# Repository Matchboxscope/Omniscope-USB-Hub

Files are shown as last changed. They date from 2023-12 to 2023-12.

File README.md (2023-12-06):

# SL2.1A Type-C Hub

Based on: https://github.com/Hugoyhu/SL2.1A-Type-C-Hub

A simple 4-port USB2 hub based on the SL2.1A design.
This board is designed in KiCAD v7! It is based off an earlier [2021 design](https://github.com/Hugoyhu/Hack-Club-Zephyr-USB-Hub) with USB-A outputs.

This revises the board to provide USB2 Type-C outputs. By default, the schematic provides circuitry for default USB power (500mA) but resistor values can be changed to provide higher output current if available through external power.

Schematic Capture
PCB Render
Assembled OSHPark After Dark

These boards have been tested and built with OSHPark After Dark service.

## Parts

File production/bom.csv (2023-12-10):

Designator | Footprint | Quantity | Value | LCSC Part #
C1, C11, C5, C7, C9 | 0805 | 5 | 100nF
C10, C4, C6, C8 | 0805 | 4 | 1uF
C2, C3 | 0805 | 2 | 10uF
D1 | 1206 | 1 | SD1206T020S1R0
D2 | 1206 | 1 | LED_Small
H1, H2 | MountingHole_3.2mm_M3_ISO14580 | 2 | MountingHole
J1 | USB_C_Receptacle_HRO_TYPE-C-31-M-12 | 1 | USB_C_Receptacle_USB2.0
J2, J3, J4, J5 | USB_C_Plug_UTC009-C12 | 4 | USB_C_Receptacle_USB2.0
R1, R2 | 0805 | 2 | 5.1K
R10, R3, R4, R5, R6, R7, R8, R9 | 0805 | 8 | 56K
R11 | 0805 | 1 | 100
U1 | SOIC-16_4.55x10.3mm_P1.27mm | 1 | SL2.1A

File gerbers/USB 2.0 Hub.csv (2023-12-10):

Id | Designator | Footprint | Quantity | Designation | Supplier and ref
1 | C4,C6,C10,C8 | C_0805_2012Metric_Pad1.18x1.45mm_HandSolder | 4 | 1uF
2 | H2,H1 | MountingHole_3.2mm_M3_ISO14580 | 2 | MountingHole
3 | R11 | R_0805_2012Metric_Pad1.20x1.40mm_HandSolder | 1 | 100
4 | C1,C9,C11,C5,C7 | C_0805_2012Metric_Pad1.18x1.45mm_HandSolder | 5 | 100nF
5 | R1,R2 | R_0805_2012Metric_Pad1.20x1.40mm_HandSolder | 2 | 5.1K
6 | D2 | LED_1206_3216Metric_Pad1.42x1.75mm_HandSolder | 1 | LED_Small
7 | R6,R4,R10,R3,R5,R8,R9,R7 | R_0805_2012Metric_Pad1.20x1.40mm_HandSolder | 8 | 56K
8 | J2,J3,J5,J4 | USB_C_Plug_UTC009-C12 | 4 | USB_C_Receptacle_USB2.0
9 | C2,C3 | C_0805_2012Metric_Pad1.18x1.45mm_HandSolder | 2 | 10uF
10 | U1 | SOIC-16_4.55x10.3mm_P1.27mm | 1 | SL2.1A
11 | D1 | D_1206_3216Metric_Pad1.42x1.75mm_HandSolder | 1 | SD1206T020S1R0
12 | J1 | USB_C_Receptacle_HRO_TYPE-C-31-M-12 | 1 | USB_C_Receptacle_USB2.0

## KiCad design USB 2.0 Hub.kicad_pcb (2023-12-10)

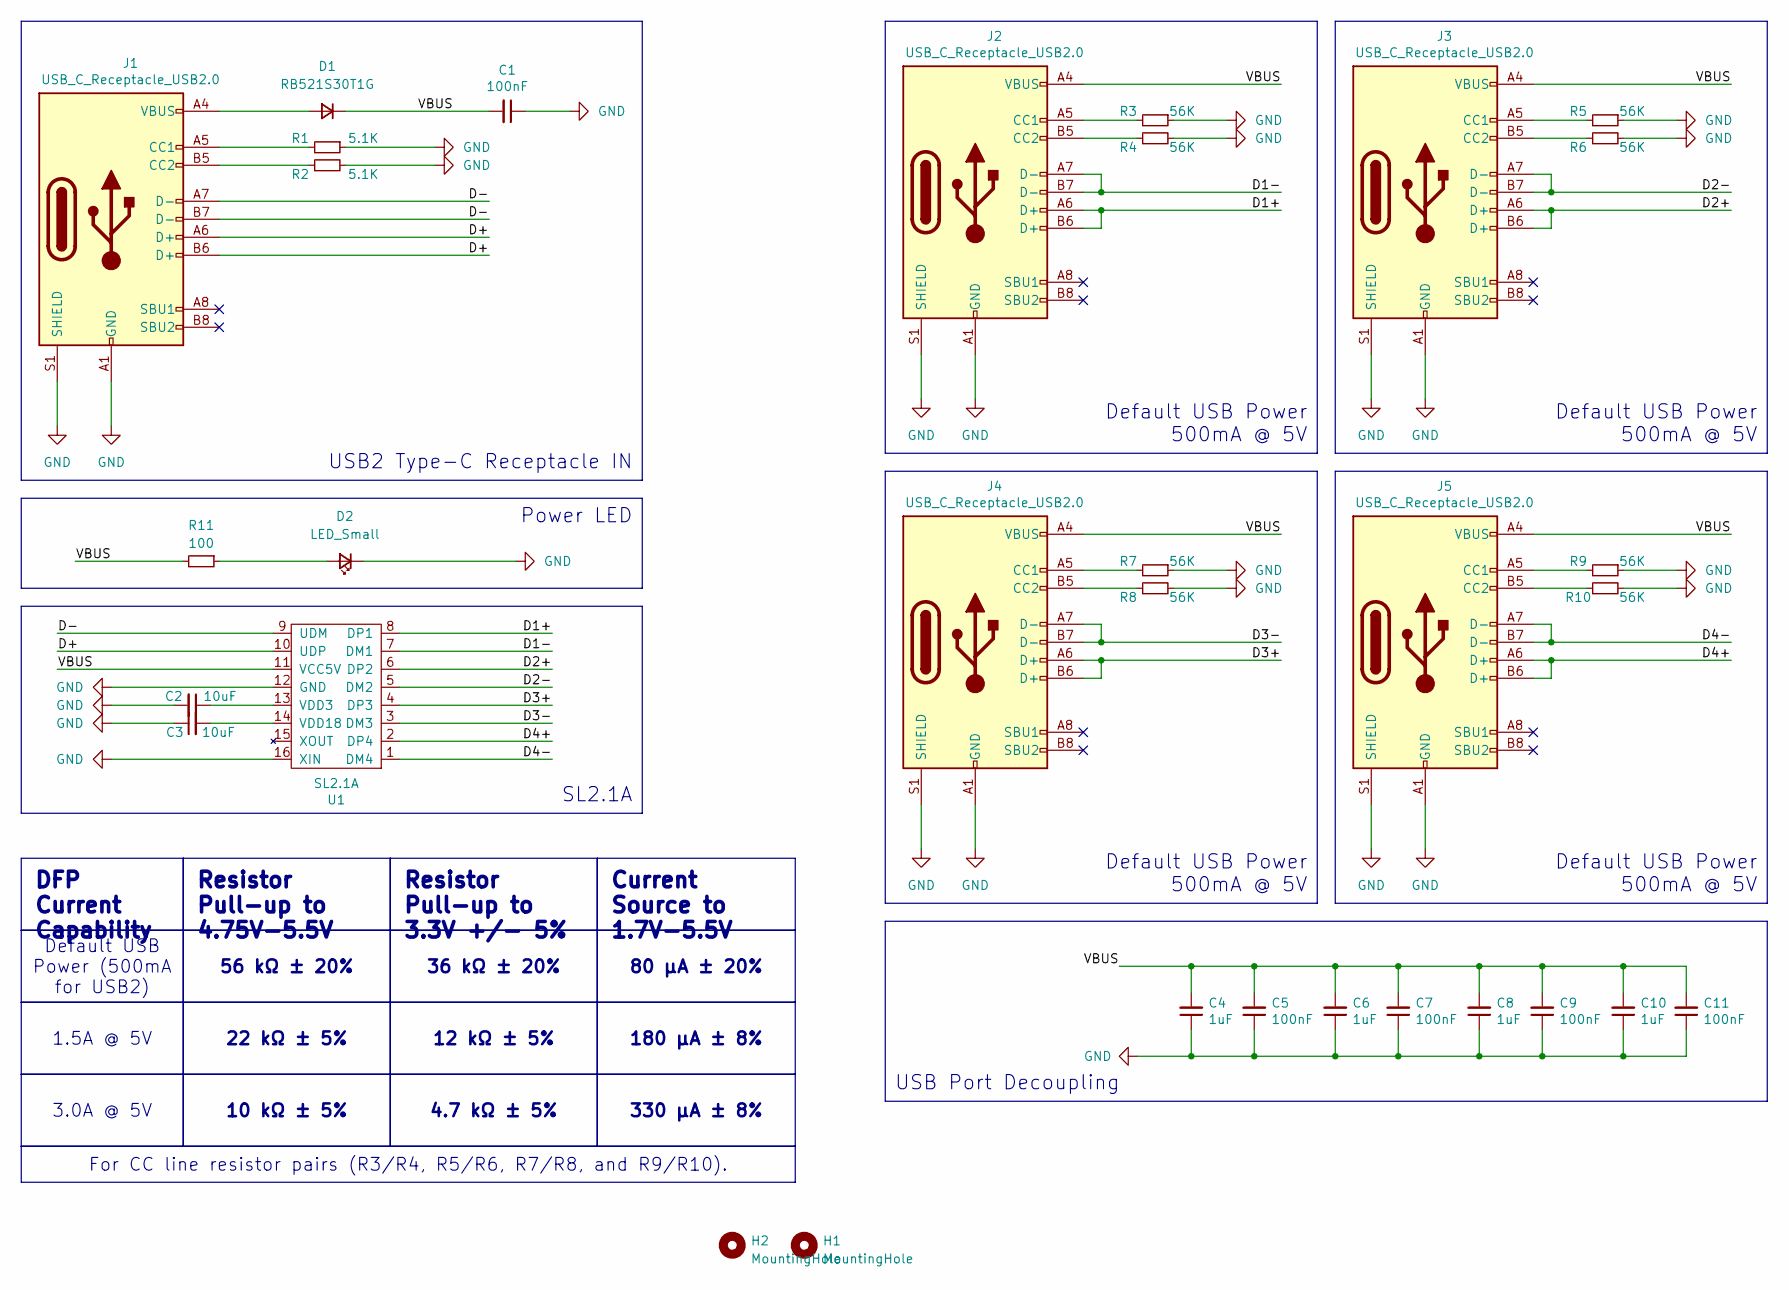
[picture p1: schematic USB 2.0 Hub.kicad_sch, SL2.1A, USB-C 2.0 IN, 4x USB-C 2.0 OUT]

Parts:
C1, C5, C7, C9, C11: 100nF; C_0805_2012Metric_Pad1.18x1.45mm_HandSolder
C2, C3: 10uF; C_0805_2012Metric_Pad1.18x1.45mm_HandSolder
C4, C6, C8, C10: 1uF; C_0805_2012Metric_Pad1.18x1.45mm_HandSolder
D1: RB521S30T1G; D_SOD-523
D2: LED_Small; LED_1206_3216Metric_Pad1.42x1.75mm_HandSolder
H1, H2: MountingHole; MountingHole_3.2mm_M3_ISO14580
J1: USB_C_Receptacle_USB2.0; USB_C_Receptacle_HRO_TYPE-C-31-M-12
J2, J3, J4, J5: USB_C_Receptacle_USB2.0; USB_C_Receptacle_U261-241N-4BS2SS
R1, R2: 5.1K; R_0805_2012Metric_Pad1.20x1.40mm_HandSolder
R3, R4, R5, R6, R7, R8, R9, R10: 56K; R_0805_2012Metric_Pad1.20x1.40mm_HandSolder
R11: 100; R_0805_2012Metric_Pad1.20x1.40mm_HandSolder
U1: SL2.1A; SOIC-16_4.55x10.3mm_P1.27mm

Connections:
/D1+: J2.A6 (D+), J2.B6 (D+), U1.8 (DP1)
/D1-: J2.A7 (D-), J2.B7 (D-), U1.7 (DM1)
/D2+: J3.A6 (D+), J3.B6 (D+), U1.6 (DP2)
/D2-: J3.A7 (D-), J3.B7 (D-), U1.5 (DM2)
/D3+: J4.A6 (D+), J4.B6 (D+), U1.4 (DP3)
/D3-: J4.A7 (D-), J4.B7 (D-), U1.3 (DM3)
/D4+: J5.A6 (D+), J5.B6 (D+), U1.2 (DP4)
/D4-: J5.A7 (D-), J5.B7 (D-), U1.1 (DM4)
/D+: J1.A6 (D+), J1.B6 (D+), U1.10 (UDP)
/D-: J1.A7 (D-), J1.B7 (D-), U1.9 (UDM)
/VBUS: C1.2, C4.2, C5.2, C6.2, C7.2, C8.2, C9.2, C10.2, C11.2, D1.1 (K), J2.A4 (VBUS), J2.A9 (VBUS), J2.B4 (VBUS), J2.B9 (VBUS), J3.A4 (VBUS), J3.A9 (VBUS), J3.B4 (VBUS), J3.B9 (VBUS), J4.A4 (VBUS), J4.A9 (VBUS), J4.B4 (VBUS), J4.B9 (VBUS), J5.A4 (VBUS), J5.A9 (VBUS), J5.B4 (VBUS), J5.B9 (VBUS), R11.2, U1.11 (VCC5V)
GND: C1.1, C2.2, C3.1, C4.1, C5.1, C6.1, C7.1, C8.1, C9.1, C10.1, C11.1, D2.1 (K), J1.A1 (GND), J1.A12 (GND), J1.B1 (GND), J1.B12 (GND), J1.S1 (SHIELD), J2.A1 (GND), J2.A12 (GND), J2.B1 (GND), J2.B12 (GND), J2.S1 (SHIELD), J3.A1 (GND), J3.A12 (GND), J3.B1 (GND), J3.B12 (GND), J3.S1 (SHIELD), J4.A1 (GND), J4.A12 (GND), J4.B1 (GND), J4.B12 (GND), J4.S1 (SHIELD), J5.A1 (GND), J5.A12 (GND), J5.B1 (GND), J5.B12 (GND), J5.S1 (SHIELD), R1.1, R2.2, R3.1, R4.2, R5.1, R6.2, R7.1, R8.2, R9.1, R10.2, U1.12 (GND), U1.16 (XIN)
unnamed: D1.2 (A), J1.A4 (VBUS), J1.A9 (VBUS), J1.B4 (VBUS), J1.B9 (VBUS)
unnamed: D2.2 (A), R11.1
unnamed: J1.A5 (CC1), R1.2
unnamed: J1.B5 (CC2), R2.1
unnamed: J2.A5 (CC1), R3.2
unnamed: J2.B5 (CC2), R4.1
unnamed: J3.A5 (CC1), R5.2
unnamed: J3.B5 (CC2), R6.1
unnamed: J4.A5 (CC1), R7.2
unnamed: J4.B5 (CC2), R8.1
unnamed: J5.A5 (CC1), R9.2
unnamed: J5.B5 (CC2), R10.1
unnamed: C2.1, U1.13 (VDD3)
unnamed: C3.2, U1.14 (VDD18)

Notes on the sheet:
Resistor Pull-up to 4.75V-5.5V
For CC line resistor pairs (R3/R4, R5/R6, R7/R8, and R9/R10).
22 kΩ ± 5%
12 kΩ ± 5%
330 μA ± 8%
Current Source to 1.7V-5.5V
4.7 kΩ ± 5%
36 kΩ ± 20%
DFP Current Capability
56 kΩ ± 20%
80 μA ± 20%
Resistor Pull-up to 3.3V +/- 5%
180 μA ± 8%
1.5A @ 5V
10 kΩ ± 5%
3.0A @ 5V
Default USB Power (500mA for USB2)
SL2.1A
Default USB Power 500mA @ 5V
USB2 Type-C Receptacle IN
USB Port Decoupling
Power LED

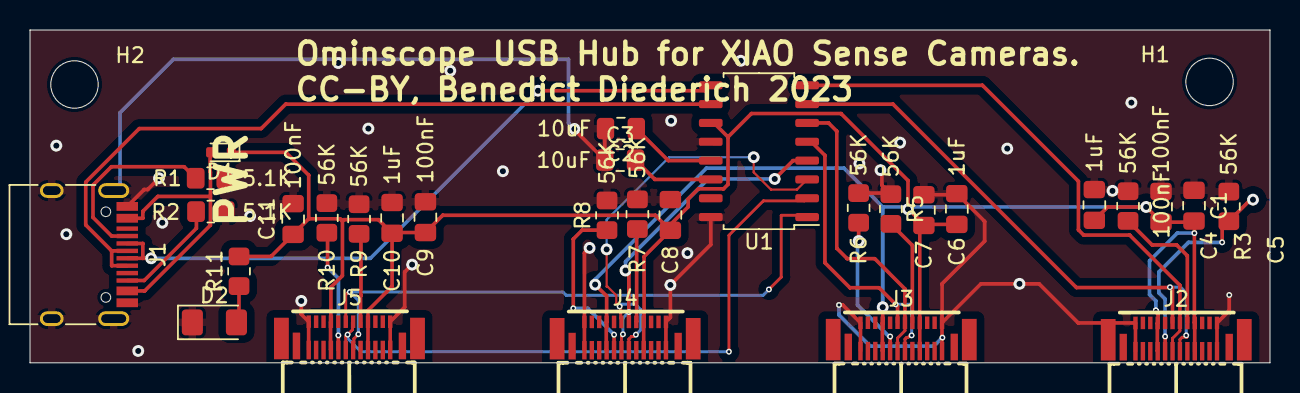
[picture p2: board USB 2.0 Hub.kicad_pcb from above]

Board: 2 copper layers, 83.7 x 22.5 mm, 32 parts (0 on the bottom side), 26 nets.

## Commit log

2023-12-06 Adjusting size to match wellplate
    [USB 2.0 Hub.kicad_pcb, USB 2.0 Hub.kicad_sch]
2023-12-08 Fixed pending connections
    [USB 2.0 Hub.kicad_pcb]
2023-12-10 Swapping USB connectors
    [USB 2.0 Hub-B_Cu.gbr, USB 2.0 Hub-B_Mask.gbr, USB 2.0 Hub-B_Paste.gbr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]
2023-12-10 updating outline
    [USB 2.0 Hub.kicad_pcb, bom.csv, designators.csv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]

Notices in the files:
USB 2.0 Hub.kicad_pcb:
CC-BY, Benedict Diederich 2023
